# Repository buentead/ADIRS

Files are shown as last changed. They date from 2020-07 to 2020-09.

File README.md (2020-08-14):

# ADIRS, BAT, Triple Gauge
This project relates to an Airbus A320 home built cockpit. It covers the following instruments:
- Battery: BAT1 and BAT2 displays in the overhead panel
- ADIRS (Air Data Inertial Reference System): The display and the rotary switches `DATA`, `SYS`, `IR1`, `IR2`, and `IR3` 
in the overhead panel. 
- Triple Gauge: drives three servos of a triple gauge such as from [Skalarki electronics Ltd](https://www.skalarki-electronics.eu/onlineshop/product/42-tripple-gauge.html).

The full project documentation can be found [here](/docu/projectDocumentation.md).

## Scope of the project

### Battery Displays
The hardware (schematics, PCB, components) required to mount the battery display into an existing overhead panel.

### ADIRS Display and Rotary Switches
The hardware (schematics, PCB, components) required to mount the ADIRS display (24 characters) as well as the decoding of the two rotary switches using analogue inputs.

### Triple Gauge
No hardware components included.

### Arduino Script
The script required to control the above displays and instrument using an Arduino MEGA 2560.

### FSUIPC LUA Script
The LUA scripts which builds the interface between the Flight Simulator and the Arduino Board.

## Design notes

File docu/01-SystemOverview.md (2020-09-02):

## System Overview

### Hardware Overview

Figure 1-1 depicts the full project from a hardware point of view.

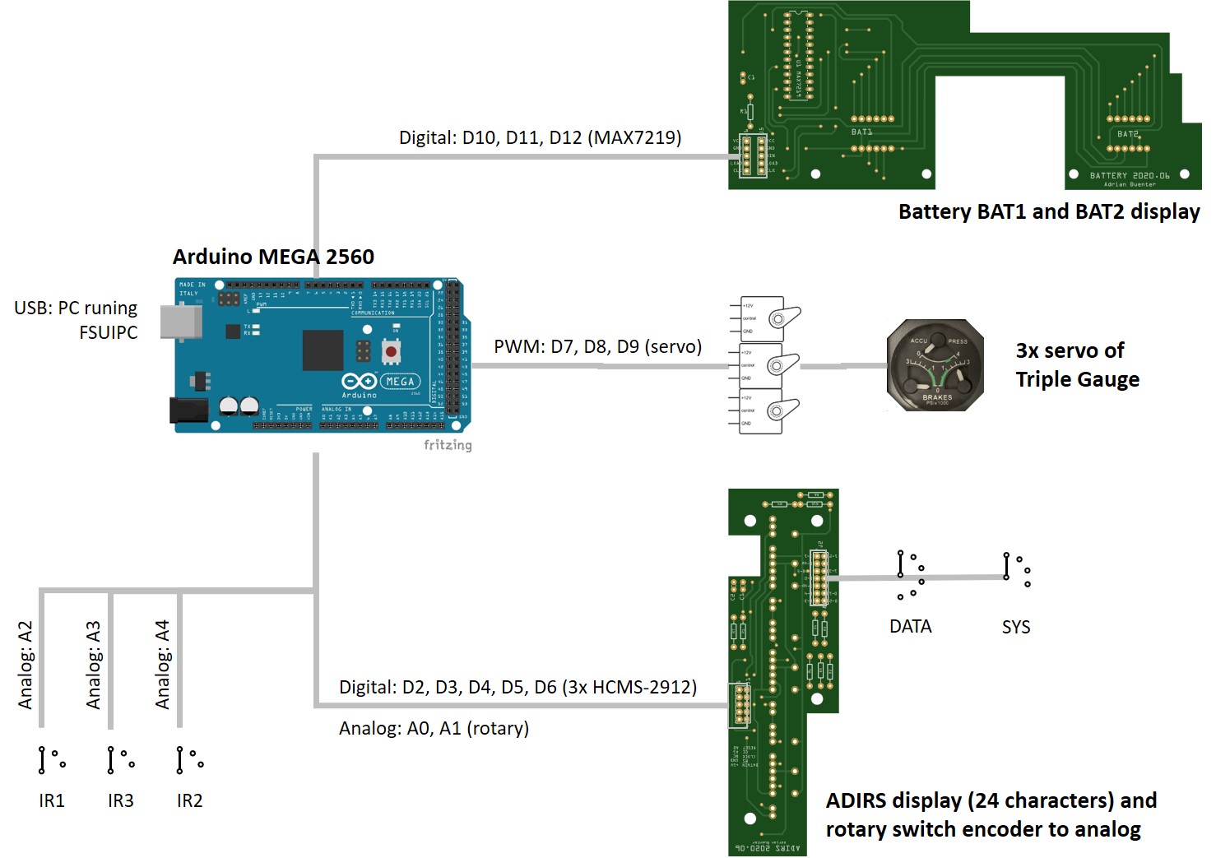
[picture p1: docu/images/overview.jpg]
Fig. 1-1 System Overview


I selected the Arduino MEGA 2560 because the digital I/O's #2 up to #13 support PWM. Therefore, I could use all 
libraries with their default PIN assignments. However, If one would like to use the Arduino UNO, it  is also possible. 
However, make sure the PINs assigned to the servo's support PWM, e.g. PIN #3, #5, and #6.

The battery and ADIRS PCB fit into the Overhead panel of Flight Deck Solutions. It is easy adapting the mechanics of the 
PCB in the [Fritzing](https://fritzing.org/) tool.

The battery PCBA uses the MAX7219 to drive the 8 digits of the battery display (2x 4 digits). Hence, any hardware that 
is compatible with the MAX7219 can be used, e.g. 
[8 Char Segment-Display with MAX7219](https://www.play-zone.ch/en/8-zeichen-segment-display-mit-max7219.html?___from_store=de) 
(2020.07).

The ADIRS PCBA includes the dot matrix display modules of Broadcom Limited. I used 3x 
[HCMS-2912](https://www.digikey.ch/product-detail/en/broadcom-limited/HCMS-2912/516-1174-5-ND/637438) (2020.07). 
Together, 24 characters are available. This is sufficient to display the present position as ` N 30°29,9'  W086°30,6' `. 
The ADIRS display in the real A320 aircraft doesn't use dot matrix display. But the Broadcom modules are the only 
display modules I found that fit into the Overhead panel. 

### Software Overview

Figure 1-2 shows the components of the ADIRS project.

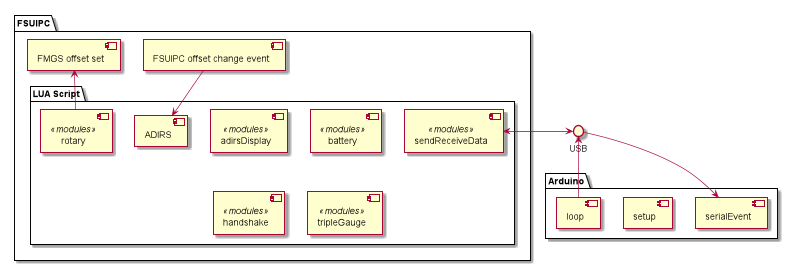
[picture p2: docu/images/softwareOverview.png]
Fig. 1-2 Software Overview


The LUA script ADIRS.lua is executed by FSUIPC or the WideFS client. The whole script is based on Flight Simulator 
offset changes and, hence, it is fully event driven.

On the Arduino side, the serialEvent() function is executed after the loop() function (see Arduino documentation). 
serialEvent() reads one full command and stores it for the loop() to be processed. Information sent back to the Flight 
Simulator are being processed within the loop().

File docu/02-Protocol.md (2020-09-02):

## Protocol
This section describes the protocol used between the Arduino board and the LUA script off the PC.

### Data Link Layer
The Ethernet shield cannot be used due to the limitation of digital and analog I/O's of the 
Arduino UNO board. Hence, message queueing such as MQTT cannot be used. Therefore, a serial
communication between the Arduino board and the LUA script has been selected.

The serial interface configuration is 115200bps, 8bit, no-parity, 1 stop bit (115200-8N1). This
gives a throughput of 11'520 bytes per second. If the battery and the ADIRS display is updated
every 200ms, the protocol size per message must not exceed 1KB - which is rather large for this
application.

Based on the above assumptions, the protocol design uses ASCII representation of the commands
sent. This allows easier testing and debugging on the protocol level.

### Message Structure
The message structure, derived from the [NMEA 0183](https://en.wikipedia.org/wiki/NMEA_0183)
used by GPS receivers for example, uses a simple ASCII serial communication structure.

- All transmitted data are printable ASCII characters (0x20 (space) to 0x7E '~')
- The message has a maximum length of 33 bytes (including the delimiters '$' and CR/LF)
- Data fields are optional
- Reserved characters are:

|ASCII|HEX|Use|
|-----|---|---|
|CR|0x0D|carriage return|
|LF|0x0A|line feed|
|$|0x24|start message character|
|,|0x2C|field delimiter|

A sample message structure shown below:
- The message starts with the character '$' (0x24)
- The next maximum five characters identify the talker ('AD' Arduino, 'FS' FlightSim) and
the type of message (two to three characters).
- All data fields are comma-delimited.
- At least one byte must be included in a data field if present.
- The message ends with 0x0D (CR) and 0x0A (LF).

The following example shows the rotary position sent from the Arduino to the PC:
- `$ADROT,0,1\r\n`

The above message will be acknowledged by the FlightSim as follows:
- `$FSACK\r\n`

### Protocol Description

The following picture shows the protocol used. Every command but `ADVER` requires an
acknowledgement before another command can be sent from either talker.

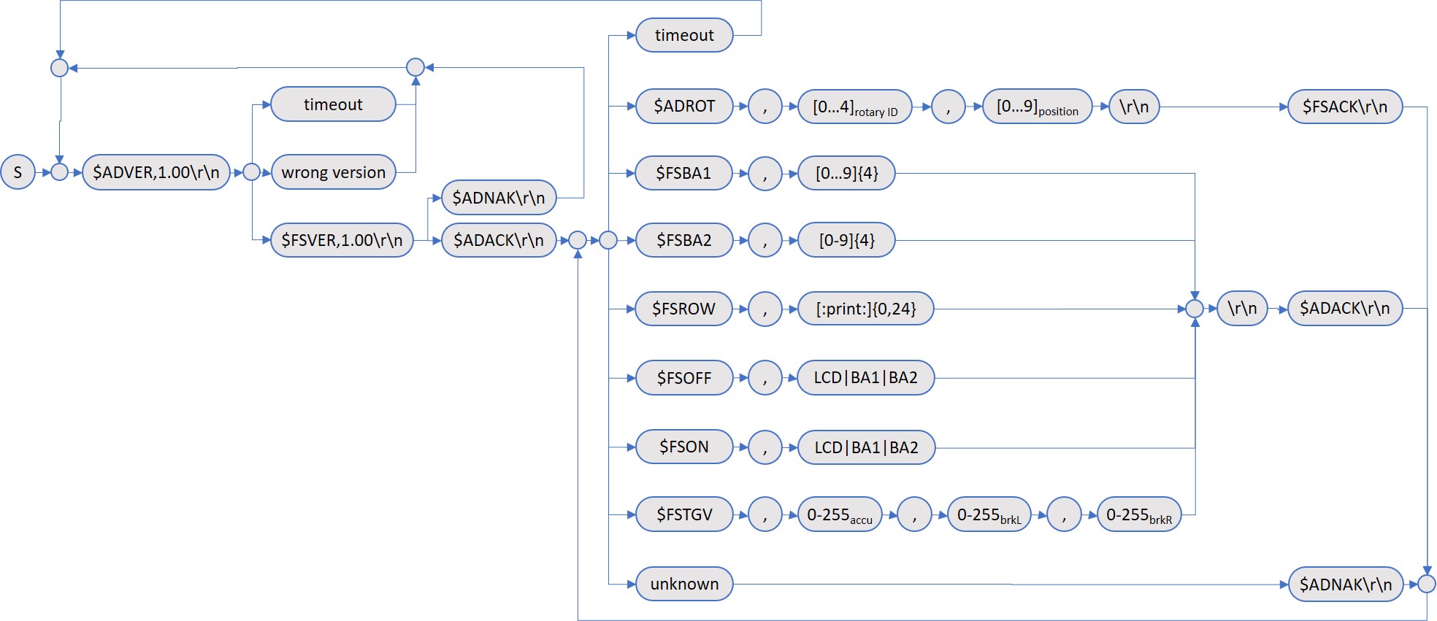
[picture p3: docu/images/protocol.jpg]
Fig. 2-1 Protocol


#### Handshake
The Arduino board initiates the communication by sending the protocol version `$ADVER,1.00\r\n`.
The FlightSim LUA script sends the version back, if it can support it, e.g. `$FSVER,1.00\r\n`.
Finaly, the Arduino board acknowledges the protocol version with `$ADACK\r\n`.

If the Arduino board doesn't receive any messages within a given time (timeout occurs), it will
resend the protocol version (heartbeat) to the FlightSim. This handles USB communication
interrupts that may occur occasionally. The picture below shows the state diagram used within
the Arduino script.

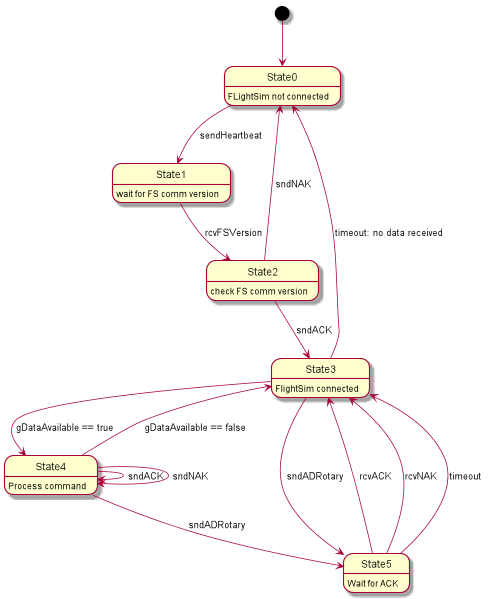
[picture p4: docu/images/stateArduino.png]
Fig. 2-2 handshake


The LUA script implements the following communication states:

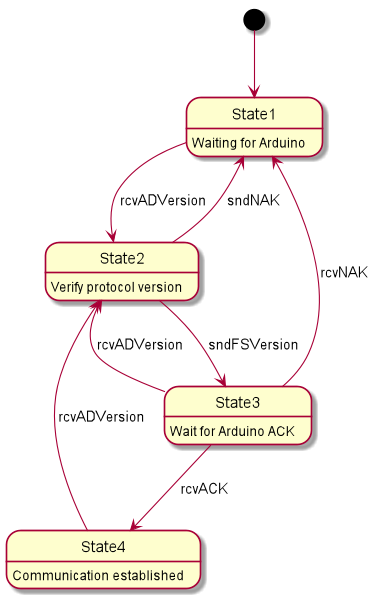
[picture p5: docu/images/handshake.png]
Fig. 2-3 handshake


#### Commands

|start|Command| |Data (regex) |end |Description|
|---|---|---|---|----|---|
|$|ADROT|,|`^[0-4],[0-9]$` |\r\n|field1: rotary switch ID: 0-DATA, 1-SYS, 2-IR1, 3-IR3, 4-IR2<br>field2: rotary position|
|$|FSBA1|,|`^[0-9]{4}$` |\r\n|Battery1 voltage (*10), e.g. 0238 for 23.8 volts|
|$|FSBA2|,|`^[0-9]{4}$` |\r\n|Battery1 voltage (*10), e.g. 0238 for 23.8 volts|
|$|FSROW|,|`^[\x20-\x7e]{0,24}$` |\r\n|Display text in ADIRS|
|$|FSOFF|,|`^(LCD\|BA1\|BA2)$`|\r\n|Switch OFF ADIRS, battery1, or battery2 display|
|$|FSON |,|`^(LCD\|BA1\|BA2)$`|\r\n|Switch OFF ADIRS, battery1, or battery2 display|
|$|FSTGV|,|0-255,0-255,0-255 |\r\n|Triple gauge servo values (0-255)<br>1. value: ACCU<br>2. value: BREAK left<br>3. value: BREAK right|
|$|ADACK| | |\r\n|Arduino confirms message received|
|$|ADNAK| | |\r\n|Arduino rejects received message|
|$|FSACK| | |\r\n|FlightSim confirms message received|
|$|FSNAK| | |\r\n|FlightSim rejects received message|

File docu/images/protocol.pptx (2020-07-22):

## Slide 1

timeout

timeout

$ADNAK\r\n

$ADROT

,

0data|1sys

,

[0…9]position

S

$ADVER,1.00\r\n

wrong version

$FSBA1

,

strBAT1[4]

$FSVER,1.00\r\n

$ADACK\r\n

$FSBA2

,

strBAT2[4]

\r\n

$ADACK\r\n

$FSROW

,

char[0…24]

$FSOFF

,

LCD|BA1|BA2

$FSON

,

LCD|BA1|BA2

unknown

$ADNAK\r\n

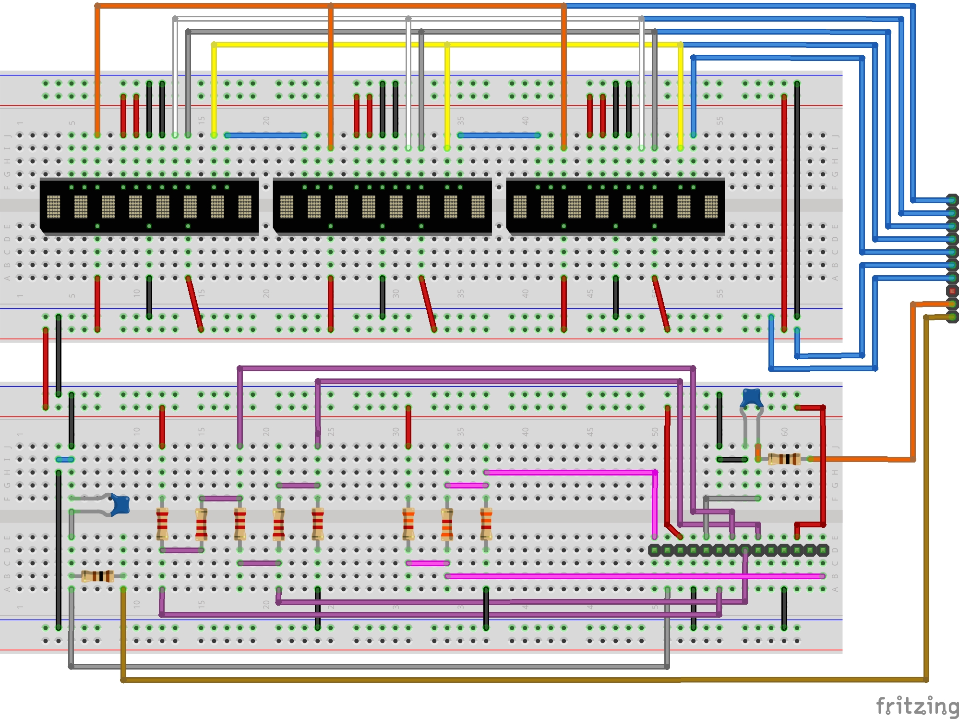
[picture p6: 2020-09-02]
hardware/adirs/ADIRS_bb.jpg

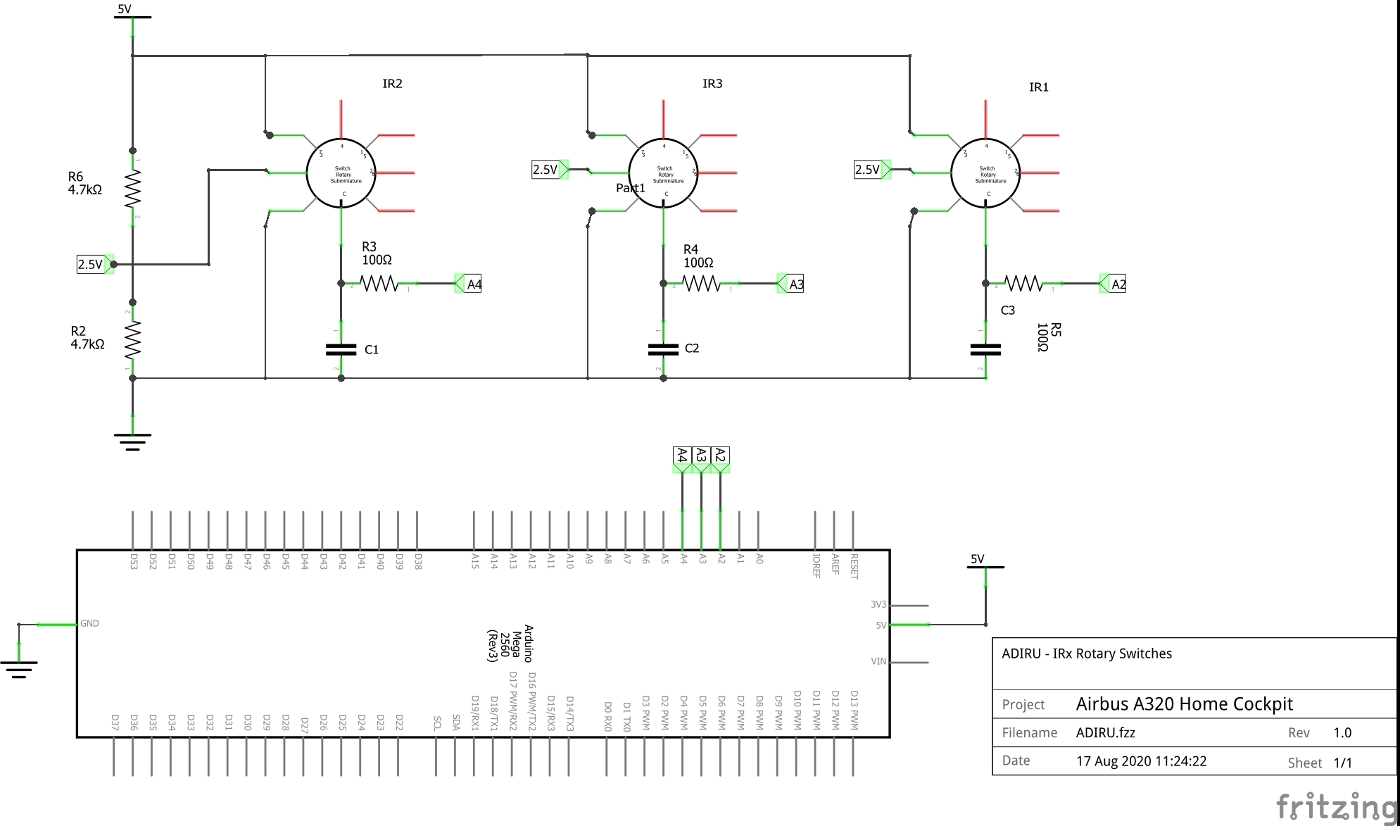
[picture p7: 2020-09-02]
hardware/schema/ADIRU_schem.jpg

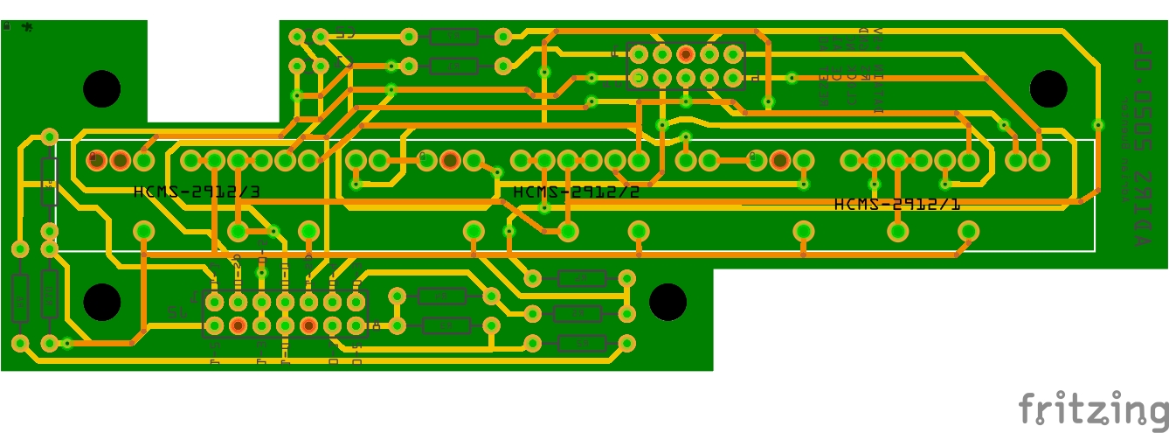
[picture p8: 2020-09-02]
hardware/adirs/ADIRS_pcb.jpg

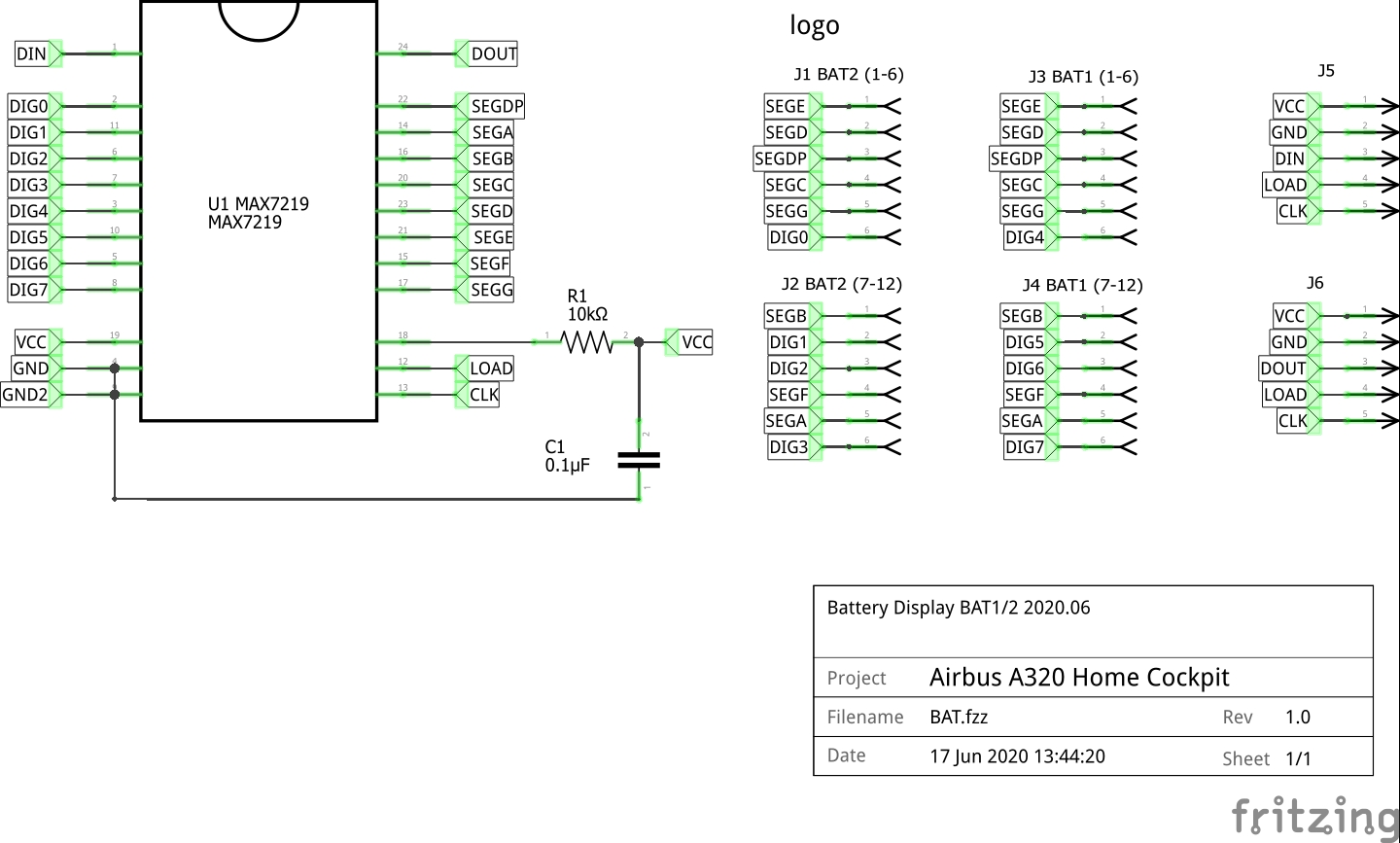
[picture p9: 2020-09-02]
hardware/schema/BAT_schem.jpg

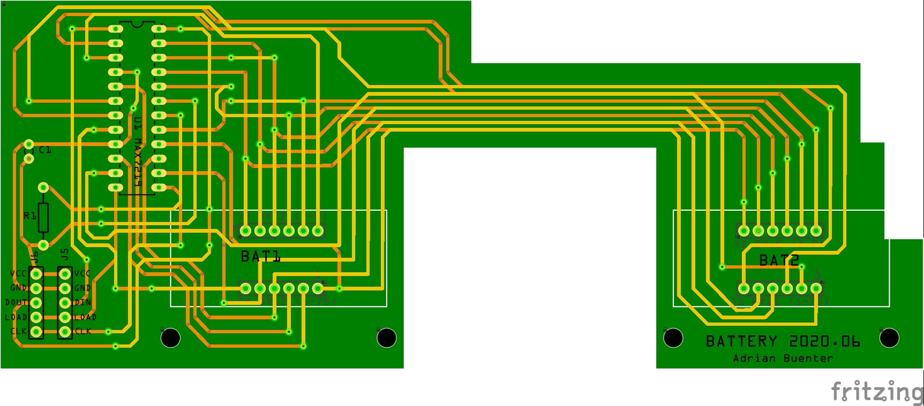
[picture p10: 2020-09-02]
hardware/battery/BAT_pcb.jpg

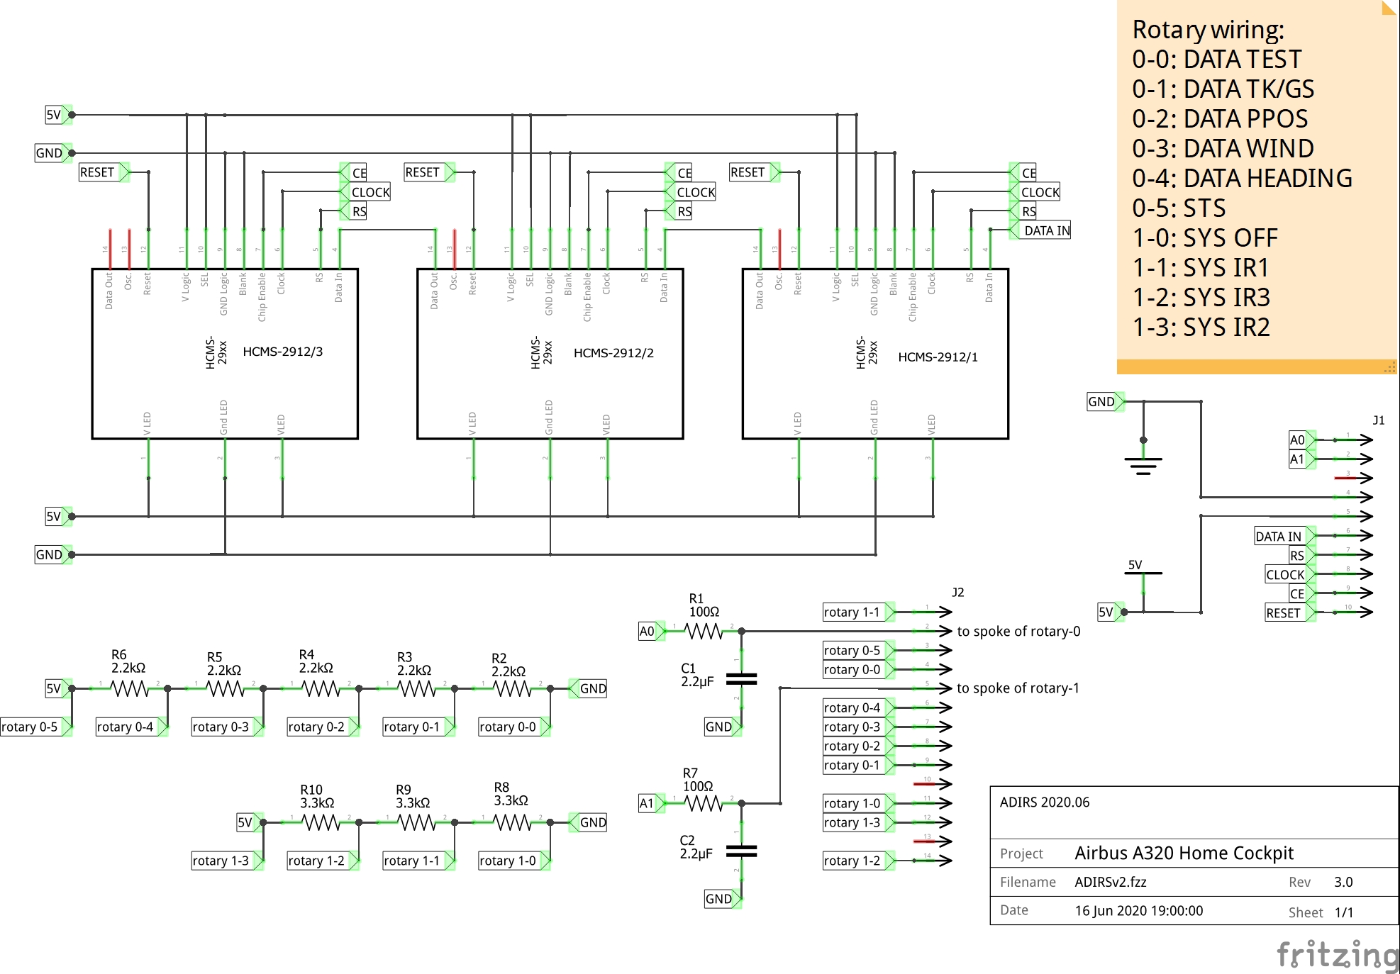
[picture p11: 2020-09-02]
hardware/schema/ADIRS_schem.jpg

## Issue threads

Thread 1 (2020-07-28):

Heading inaccurate

buentead, 2020-07-28:
The heading (and track) shown on the ADIRS display doesn't correspond with the A320 Navigation Display.

Possible cause: magnetic derivation must be included.

buentead, 2020-08-03:
Magnetic variation included in v0.2.0. It was alos necessary to update the P3D v4.5 BGL file of magnetic heading corrections.

Closed 2020-08-03.

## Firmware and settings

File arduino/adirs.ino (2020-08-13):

/* -------------------------------------------------------------------
   adirs.ino
   -------------------------------------------------------------------
   Arduino scripts processing data received from the FSUIPC LUA script
   ADIRS.lua
*/

#include <Wire.h>
#include <LedDisplay.h>
#include <max7219.h>
#include <Servo.h>

// define rotary switches
#define DATA_POS 6
#define SYS_POS 4
#define IR1_POS 3
#define IR2_POS 3
#define IR3_POS 3
#define ROTARY_NEWVAL 0
#define ROTARY_OLDVAL 1
#define ROTARY_DEBOUNCE 2
#define ROTARY_RANGE 3
#define ROTARY_ADDR 4
#define ROTARY_DEBOUNCE_MIN 2

// Protocol versions
const String  VERSION    = "1.00";         // expected protocol version from FlightSimulator
const String  TALKER     = "AD";
const String  MSGVER     = "VER";
const int     MAXADIRS   = 24;
const int     MAXINBUF   = 100;
const int     MAXDATA    = 5;
const int     MAXANALOG  = 1024;
const int     TIMEOUTACK = 2000;           // time in milliseconds to wait for ACK/NAK
const long    BAUDRATE   = 115200;
const long    TIMERESENDMAX = 1000000;    // timeout before version number is sent again (in milliseconds)
const uint8_t MAXBRIGHT = 6;
const byte    ACCUMIN = 0; // 10
const byte    ACCUMAX = 98; // 105
const byte    BRKLMIN = 3; // 15
const byte    BRKLMAX = 96; // 102
const byte    BRKRMIN = 103; // 111
const byte    BRKRMAX = 8; // 24

// Dot matrix display configuration
LedDisplay adirs = LedDisplay(2, 3, 4, 5, 6, MAXADIRS);

// Define 8-digit display configuration for battery voltage
MAX7219 bat;

// Servo's of Triple Gauge
Servo servoAccu;
Servo servoBrkL;
Servo servoBrkR;

// Global variables
unsigned long gTimeResend = 0;      // time when version is being sent (again)
unsigned long gTimeHeartbeat = 0;   // timout to resend heartbeat
unsigned long gWaitForACK = 0;      // timer to wait for ACK/NAK
String  gSerialInput   = "";        // used to read serial data
String  gData[MAXDATA];             // ring buffer for commands received
String  gLCDRowNew     = "";        // Dot matrix display row to be displayed
char    gLCDRowSet[MAXADIRS + 1];   // Dot matrix display row currently active
boolean gDataAvailable = false;     // true: new command(s) in ring buffer available
boolean gLcdOn         = true;
boolean gBatOn[2]      = {false,false};
boolean gStartCmd      = false;     // '$' received to indicate start of new command
byte    gDataSerial    = 0;         // gData array index used by serial input
byte    gDataExe       = 0;         // gData array index used by command processor (state 4)
int     gState         = 0;         // State machine
int     gBatVolt[2]    = {0,0};     // Actual battery voltage
int     gRotary[5][5]  = {
  {0,99,0,MAXANALOG / ((DATA_POS - 1) * 2),A0},   // Rotary DISPLAY DATA
  {0,99,0,MAXANALOG / ((SYS_POS - 1) * 2),A1},    // Rotary DISPLAY SYS
  {0,99,0,MAXANALOG / ((IR1_POS - 1) * 2),A2},    // Rotary IR1
  {0,99,0,MAXANALOG / ((IR2_POS - 1) * 2),A3},    // Rotary IR2
  {0,99,0,MAXANALOG / ((IR3_POS - 1) * 2),A4}     // Rotary IR3
};
int     gRotaryWait    = 0;         // indicates which rotary switch waits for ACK/NAK

/*
   SETUP board
*/
void setup() {
  gTimeHeartbeat = millis();
  gTimeResend = millis();
  adirs.begin();
  adirs.setBrightness(MAXBRIGHT);
  bat.Begin();
  bat.MAX7219_SetBrightness(MAXBRIGHT); // min: 0, max: 15

  // start serial port at 115,2kbps and wait for port to open
  Serial.begin(BAUDRATE);
  while (!Serial) {
    ; // wait for serial port to connect. Needed for native USB port only
  }
  Serial.setTimeout(1000);      // timeout at default 1 second
  gSerialInput.reserve(MAXINBUF);    // recerve max length of inbound data
  adirs.clear();
  adirs.setCursor(0);
  adirs.print("Built by Adrian Buenter");
  servoAccu.attach(7);
  servoAccu.write(ACCUMIN);
  servoBrkL.attach(8);
  servoBrkL.write(BRKLMIN);
  servoBrkR.attach(9);
  servoBrkR.write(BRKRMIN);
  delay(4000);
  adirs.clear();
  gLCDRowSet[MAXADIRS + 1] = 0;
}

/*
   Main loop
*/
void loop() {
  byte idx;
  // Evaluate new state
  gState = fStateMachine(gState,gTimeResend,gTimeHeartbeat,gDataAvailable);
  // process data
  switch (gState) {
    case 0: // Ready to send Heartbeat with version
      gState = sendHeartbeat();
      break;
    case 2:
      idx = (gDataExe + 1) % MAXDATA;
      gState = checkProtocolVersion(VERSION,gData[idx]);
      gDataExe = idx;
      gDataAvailable = (gDataSerial != gDataExe);
      break;
    case 3:
      // Process rotary switch positions
      gState = fRotaryRead(gState);
      break;
    case 4:
      idx = (gDataExe + 1) % MAXDATA;
      if (gData[idx].substring(0,7) == "$FSLCD,") {
        fFSROW(gData[idx]);
      }
      else if (gData[idx].substring(0,7) == "$FSBA1,") {
        fFSBAx(0,gData[idx]);
      }
      else if (gData[idx].substring(0,7) == "$FSBA2,") {
        fFSBAx(1,gData[idx]);
      }
      else if (gData[idx].substring(0,6) == "$FSON,") {
        fFSON(gData[idx]);
      }
      else if (gData[idx].substring(0,7) == "$FSOFF,") {
        fFSOFF(gData[idx]);
      }
      else if (gData[idx].substring(0,7) == "$FSTGV,") {
        fFSTGV(gData[idx]);
      }
      else {
        Serial.println("$ADNAK");
      }
      gDataExe = idx;
      gDataAvailable = (gDataSerial != gDataExe);
      gTimeResend = setTimeResend(gTimeResend); // reset heartbeat timer
      // Process rotary switch positions
      gState = fRotaryRead(gState);
      break;
    case 5:
      if (gDataAvailable) {
        idx = (gDataExe + 1) % MAXDATA;
        gState = fRotaryACK(gState,gData[idx]);
        gDataExe = idx;
        gDataAvailable = (gDataSerial != gDataExe);
        gTimeResend = setTimeResend(gTimeResend); // reset heartbeat timer
      }
      break;
  }
}

/*
   Serial data received
   SerialEvent occurs when new data comes in on serial RX. This
   routine runs between each time loop() was executed
*/
void serialEvent() {
  char inChar;
  boolean waitForCRLF = true;
  while (Serial.available() && waitForCRLF) {
    inChar = (char)Serial.read();
    switch (inChar) {
      case '$':
        gSerialInput = inChar;
        gStartCmd = true;
        break;
      case '\r':
        waitForCRLF = fAddCommand(waitForCRLF);
        break;
      case '\n':
        waitForCRLF = fAddCommand(waitForCRLF);
        break;
      case '@':
        waitForCRLF = fAddCommand(waitForCRLF);
        break;
      default:
        if (gSerialInput.length() != 0 && gSerialInput.length() < MAXINBUF) {
          gSerialInput += inChar;
        }
        else if (gSerialInput.length() != 0) { // length overflow
          gSerialInput = "";
        }
    } // switch case
  } // while
}

/*
   Functions
*/

// Insert new command received
boolean fAddCommand(boolean pWaitForCRLF){
  byte    idx   = (gDataSerial + 1) % MAXDATA;
  boolean rFlag = pWaitForCRLF;
  if (gStartCmd) {
    gData[idx] = gSerialInput;
    gSerialInput = "";
    gStartCmd = false;
    rFlag = false;
    gDataSerial = idx;
    gDataAvailable = true;
  }
  return rFlag;
}

// Read position of rotary switches
int fRotaryRead(int state){
  int newState = state;
  int val = 0;
  char data[40];
  // read rotary of 'DATA' ,'SYS', 'IR1', 'IR2', and 'IR3'
  for (int i=0; i < 5; i++){
    val = analogRead(gRotary[i][ROTARY_ADDR]);
    // Calculate new rotary position based on analog value
    gRotary[i][ROTARY_NEWVAL] = (((10 * val) / (2 * gRotary[i][ROTARY_RANGE])) + 5) / 10;
    if (gRotary[i][ROTARY_NEWVAL] != gRotary[i][ROTARY_OLDVAL]){
      (gRotary[i][ROTARY_DEBOUNCE])++;
      if (gRotary[i][ROTARY_DEBOUNCE] > ROTARY_DEBOUNCE_MIN){
        // new position set
        sprintf(data, "$ADROT,%d,%d", i, gRotary[i][ROTARY_NEWVAL]);
        Serial.println(data);
        gWaitForACK = millis() + TIMEOUTACK;
        gRotaryWait = i;
        newState = 5;
        break;
      }
    } else {
      // reset debounce counter
      gRotary[i][ROTARY_DEBOUNCE] = 0;
    }
  }
  return newState;
}

// Wait for rotary switches ACK/NAK
int fRotaryACK(int state, const String& pSerialInput){
  int newState = state;
  if (pSerialInput.substring(0,6) == "$FSACK") {
    gRotary[gRotaryWait][ROTARY_OLDVAL]   = gRotary[gRotaryWait][ROTARY_NEWVAL];
    gRotary[gRotaryWait][ROTARY_DEBOUNCE] = 0;
    gRotaryWait = 0;
    gWaitForACK = 0;
    newState    = 3;
  }
  else if (pSerialInput.substring(0,6) == "$FSACK") {
    gRotaryWait = 0;
    gWaitForACK = 0;
    newState    = 3;
  }
  return newState;
}

// Update State Machine
int fStateMachine(int state, unsigned long timeResend, unsigned long timeHeartbeat, boolean dataAvailable){
  int newState = state;
  switch (state) {
    case 0: // send heartbeat with version
      // no action required
      break;
    case 1: // wait for FS protocol version
      if (dataAvailable){
        newState = 2;   // FS protocol version to be verified
      }
      else if (isTimeout(timeHeartbeat)){
        newState = 0;   // send heartbeat with version
      }
      break;
    case 2: // check FS comm version
      newState = 1;     // in case state 2 wasn't successfully processed
      break;
    case 3: // FlightSim connected
      if (dataAvailable){
        newState = 4;   // read command
      }
      else if (isTimeout(timeResend)){
        newState = 0;
        gRotary[0][ROTARY_OLDVAL] = 99;
        gRotary[1][ROTARY_OLDVAL] = 99;
      }
      break;
    case 4: // process command(s) received
      if (!dataAvailable){
        newState = 3;
      }
      break;
    case 5: // wait for ACK/NAK
      if (gWaitForACK < millis()) {
        // waiting for ACK/NAK timed out
        gWaitForACK = 0;
        newState = 3;
      }
      break;
  }
  return newState;
}

// receive protocol version
int checkProtocolVersion(String protVers, const String& pSerialInput) {
  int newState = 0;
  if (pSerialInput.substring(0,7) == "$FSVER," && pSerialInput.substring(7,7 + protVers.length()) == protVers){
    Serial.println("$ADACK");
    gTimeResend = setTimeResend(gTimeResend); // reset heartbeat timer
    newState = 3;
  }
  else {
    Serial.println("$ADNACK");
  }
  return newState;
}

// Send heartbeat when x-time passed
int sendHeartbeat(){
  int newState = 1;
  Serial.println("$" + TALKER + MSGVER + "," + VERSION);
  gTimeHeartbeat = setTimeResend(gTimeHeartbeat);
  return newState;
}

// Set next timeout value
unsigned long setTimeResend(unsigned long oldTimeResend) {
  unsigned long timeResend;                   // time to resend version number
  timeResend = millis() + TIMERESENDMAX; // set next time period
  if (oldTimeResend > timeResend) {
    // Arduino is running more than 50 days (overflow of unsigned long), reset counter
    while (millis() > TIMERESENDMAX) {        // wait until actual clock also overflows, should be within <= timeResendMax
      delay(200);
    }
    timeResend = millis() + TIMERESENDMAX;
  }
  return timeResend;
}


// Verify if timout occurs
boolean isTimeout(unsigned long oldTimeResend) {
  boolean rc = false;
  if (oldTimeResend <= millis()) {
    rc = true;
  }
  else if (millis() < 5000 && oldTimeResend > (5000 + TIMERESENDMAX)) { // if reported milliseconds is < 5 seconds and board not just started (running > 5 seconds), probably an overflow occured (~50 days)
    rc = true;
  }
  //Serial.println("isTimeout: " + String(rc) + ", old:" +String(oldTimeResend) + ", act:" +String(millis()));
  return rc;
}

/*
   PROCESS COMMANDS
*/

// $FSLCD - set dot matrix text
void fFSROW(const String& pSerialInput) {
  String row = pSerialInput.substring(7);
  gLCDRowNew = row.substring(0,MAXADIRS);
  displayADIRS();
  Serial.println("$ADACK");
}
// write text to dot matrix display
void displayADIRS(){
  // Sending all 24 characters (e.g. adirs.print("string")) takes about 265ms - 270ms.
  // To ensure fast update cycles, only characters that changed will be sent to the display.
  byte strLen = gLCDRowNew.length();
  if (gLcdOn){
    // process buffer and send character if changed
    for (int i = 0; i < MAXADIRS; i++){
      if (i < strLen){
        // compare old buffer with new buffer
        if (gLCDRowSet[i] != gLCDRowNew[i]){
          gLCDRowSet[i] = gLCDRowNew[i];
          adirs.setCursor(i);
          adirs.write(gLCDRowSet[i]);
        }
      }
      else {
        // new buffer shorter than max buffer -> fill with space
        if (gLCDRowSet[i] != ' '){
          gLCDRowSet[i] = ' ';
          adirs.setCursor(i);
          adirs.write(gLCDRowSet[i]);
        }
      }
    }
  }
}

// $FSBAx - set 4 digit display
void fFSBAx(int batIdx, const String& pSerialInput){
  if (pSerialInput.length() == 11){
    gBatVolt[batIdx] = pSerialInput.substring(7,11).toInt();
    displayVolt();
    Serial.println("$ADACK");
  }
  else {
    Serial.println("$ADNACK");
  }
}
// write voltage to 7-seg, 8 digit, serial display
void displayVolt(){
  char data[17];          // 8 digits, 8 decimal points, termination 0x00
  char batx[2][9];        // 4 digits, 4 decimal places, termination 0x00
  // process each BAT
  for (int i=0; i <= 1; i++){
    if (gBatOn[i]){
      sprintf(batx[i], "%3d.%d", gBatVolt[i]/10, gBatVolt[i]%10);
    }
    else {
      batx[i][0] = 0;     // empty string
    }
  }
  sprintf(data, "%4s%4s", batx[0], batx[1]);
  bat.DisplayText(data, 1);
}

// Displays on
void fFSON(const String& pSerialInput){
  if (pSerialInput.substring(6,9) == "LCD"){
    gLcdOn = true;
    displayADIRS();
  }
  else if (pSerialInput.substring(6,9) == "BA1"){
    gBatOn[0] = true;
    displayVolt();
  }
  else if (pSerialInput.substring(6,9) == "BA2"){
    gBatOn[1] = true;
    displayVolt();
  }
  Serial.println("$ADACK");
}

// Displays off
void fFSOFF(const String& pSerialInput){
  if (pSerialInput.substring(7,10) == "LCD"){
    gLcdOn = false;
    adirs.clear();
    for (int i = 0; i < MAXADIRS; i++){
      gLCDRowSet[i] = ' ';
    }
  }
  else if (pSerialInput.substring(7,10) == "BA1"){
    gBatOn[0] = false;
    displayVolt();
  }
  else if (pSerialInput.substring(7,10) == "BA2"){
    gBatOn[1] = false;
    displayVolt();
  }
  Serial.println("$ADACK");
}

// Set Triple Gauge Servo's
void fFSTGV(const String& pSerialInput) {
  byte i1 = 0;
  byte i2 = 0;
  int  tgv = 0;

  i1 = pSerialInput.indexOf(',', 7);
  tgv = (pSerialInput.substring(7, i1)).toInt();
  servoAccu.write(map(tgv,0,255,ACCUMIN,ACCUMAX));
  i1++;
  i2 = pSerialInput.indexOf(',', i1);
  tgv = (pSerialInput.substring(i1, i2)).toInt();
  servoBrkL.write(map(tgv,0,255,BRKLMIN,BRKLMAX));
  i2++;
  tgv = (pSerialInput.substring(i2)).toInt();
  servoBrkR.write(map(tgv,0,255,BRKRMIN,BRKRMAX));
  Serial.println("$ADACK");
}

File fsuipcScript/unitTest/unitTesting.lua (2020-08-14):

----------------------------------------------------------------------
-- unitTesting.lua
----------------------------------------------------------------------
-- Testing all functions of the modules called by the main FSUIPC scripts ADIRS.lua

lunit     = require('luaunit')
bat       = require('lib/battery')
rotary    = require('lib/rotary')
adirs     = require('lib/adirsDisplay')
tg        = require('lib/tripleGauge')
handshake = require('lib/handshake')
data      = require('lib/sendReceiveData')

bat.setDataCom(data)                     -- set instance to send data
rotary.setDataCom(data)                  -- set instance to send data
adirs.setDataCom(data)                   -- set instance to send data
tg.setDataCom(data)                      -- set instance to send data
handshake.setDataCom(data)               -- set instance to send data

function sleep(n)  -- seconds
    local t0 = os.clock() + 0.5
    while os.clock() - t0 <= n do end
end

Test010Handshake = {}
    -- establish connection
    local _msg  = ''
    local _init = false
    local _bat  = ''
    local _volt = ''
    local _stat  = 0
    function Test010Handshake:test010()
        _msg = data.rcvData('ADVer,1.00')
        lunit.assertEquals(_msg,'ADVer,1.00')
        lunit.assertEquals(handshake.arduinoConnected(),false)
        _msg = data.rcvData('ADVER,1.00')
        lunit.assertEquals(_msg,'ADVER,1.00')
        data.rcvData('ADACK')
        lunit.assertEquals(handshake.arduinoConnected(),true)
        _bat, _volt, _stat = bat.evtBATxVolt('BA1',0001)
        lunit.assertEquals(_bat,'BA1')
        lunit.assertEquals(_volt,0001)
        lunit.assertEquals(_stat,2)
        _bat, _volt, _stat = bat.evtBATxVolt('BA2',0002)
        lunit.assertEquals(_bat,'BA2')
        lunit.assertEquals(_volt,0002)
        lunit.assertEquals(_stat,2)
    end
-- end of table 'TestInitialize'

Test020Battery = {}
    local _bat  = ''
    local _volt = ''
    local _show = false
    local _stat  = 0
    -- Switch immediately ON/OFF -> OFF
    function Test020Battery:test010()
        bat.evtBATxOFF('BA1')
        bat.evtBATxON('BA1')
        _bat, _show, _stat = bat.evtBATxOFF('BA1')
        lunit.assertEquals(_bat,'BA1')
        lunit.assertEquals(_show,false)
        lunit.assertEquals(_stat,1)
    end
    -- Switch ON with one NAK -> ON
    function Test020Battery:test020()
        _bat, _show, _stat = bat.evtBATxON('BA1')
        lunit.assertEquals(_bat,'BA1')
        lunit.assertEquals(_show,true)
        lunit.assertEquals(_stat,2)
        _bat, _stat = bat.sndBATData()
        lunit.assertEquals(_bat,'BA1')
        lunit.assertEquals(_stat,3)
        data.rcvData('ADNAK')
        _bat, _stat = bat.sndBATData()
        lunit.assertEquals(_bat,'BA1')
        lunit.assertEquals(_stat,3)
        data.rcvData('ADACK')
        _bat, _, _stat = bat.evtBATxON('BA1')
        lunit.assertEquals(_bat,'BA1')
        lunit.assertEquals(_stat,11)
    end
    -- Send Volt with one NAK and one ACK, receive new Volt
    function Test020Battery:test100()
        _bat, _volt, _stat = bat.evtBATxVolt('BA1', 123)
        lunit.assertEquals(_bat,'BA1')
        lunit.assertEquals(_volt,123)
        lunit.assertEquals(_stat,11)
        _bat, _volt, _stat = bat.sndBATxVolt('BA1')
        lunit.assertEquals(_bat,'BA1')
        lunit.assertEquals(_volt,123)
        lunit.assertEquals(_stat,12)
        _bat, _volt, _stat = bat.evtBATxVolt('BA1', 4567)
        lunit.assertEquals(_bat,'BA1')
        lunit.assertEquals(_volt,4567)
        lunit.assertEquals(_stat,11)
        data.rcvData('ADACK')
        _bat, _volt, _stat = bat.sndBATxVolt('BA1')
        lunit.assertEquals(_bat,'BA1')
        lunit.assertEquals(_volt,4567)
        lunit.assertEquals(_stat,12)
        data.rcvData('ADACK')
        _bat, _, _stat = bat.evtBATxON('BA1')
        lunit.assertEquals(_bat,'BA1')
        lunit.assertEquals(_stat,13)
        _bat, _volt, _stat = bat.evtBATxVolt('BA1', 890)
        lunit.assertEquals(_bat,'BA1')
        lunit.assertEquals(_volt,890)
        lunit.assertEquals(_stat,11)
    end
    -- Switch OFF with NAK and ON before sending OFF -> ON
    function Test020Battery:test200()
        bat.evtBATxOFF('BA1')
        bat.sndBATxOFF('BA1')
        data.rcvData('ADNAK')
        _bat, _show, _stat = bat.evtBATxON('BA1')
        lunit.assertEquals(_bat,'BA1')
        lunit.assertEquals(_show,true)
        lunit.assertEquals(_stat,2)
        bat.sndBATxON('BA1')
        data.rcvData('ADACK')
        _bat, _, _stat = bat.evtBATxON('BA1')
        lunit.assertEquals(_bat,'BA1')
        lunit.assertEquals(_stat,11)
    end
    -- Switch both batteries on and display volt
    function Test020Battery:test300()
        _bat, _volt, _stat = bat.evtBATxVolt('BA2', 275)
        lunit.assertEquals(_bat,'BA2')
        lunit.assertEquals(_volt,275)
        lunit.assertEquals(_stat,2)
        _bat, _volt, _stat = bat.evtBATxVolt('BA1', 279)
        lunit.assertEquals(_bat,'BA1')
        lunit.assertEquals(_volt,279)
        lunit.assertEquals(_stat,11)
        bat.evtBATxON('BA2')                -- switch on BA2 display
        bat.evtBATxON('BA1')                -- no impact, as BA1 is already in state 11 (previous test200)
        _bat, _stat = bat.sndBATData()      -- will send volt 27.9 of BA1
        lunit.assertEquals(_bat,'BA1')
        lunit.assertEquals(_stat,12)
        data.rcvData('ADACK')
        _bat, _stat = bat.sndBATData()      -- will switch on BA1 display
        lunit.assertEquals(_bat,'BA2')
        lunit.assertEquals(_stat,3)
        data.rcvData('ADACK')
        _bat, _stat = bat.sndBATData()      --  send volt 27.5 of BA2
        lunit.assertEquals(_bat,'BA2')
        lunit.assertEquals(_stat,12)
        data.rcvData('ADACK')
        _bat, _, _stat = bat.evtBATxON('BA2')
        lunit.assertEquals(_bat,'BA2')
        lunit.assertEquals(_stat,13)
    end
-- end of table 'TestBattery'
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

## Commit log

2020-08-03 Magnetic variation included for "Heading". ADIRS display update only if values changed. This results in approx. 7 updates per second.
2020-08-13 Three rotary switches added to support IR1, IR2, and IR3
2020-08-13 ADIRS display now dependent on the IRx rotary switches
2020-08-13 Update to handle IR1, IR2, and IR3 rotary switches
2020-08-14 Bug fixing, enhancement of unit testing
    [unitTesting.lua]
2020-08-17 IRx rotary switches added to the Overview
2020-08-17 GERBER files
2020-08-17 PCB routing
2020-08-17 Project files out of the tool 'Fritzing'
    [ADIRSv3.fz, ADIRU.fz, BAT.fz]
2020-09-02 ADIRS display initial upload
    [ADIRS.fz, ADIRSv3.fz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]
2020-09-02 Battery display initial upload
    [BAT.fz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]
2020-09-02 Hardware files reorganized
    [ADIRS.fz, ADIRSv3.fz, ADIRU.fz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]
2020-09-02 Initial bread board image loaded
